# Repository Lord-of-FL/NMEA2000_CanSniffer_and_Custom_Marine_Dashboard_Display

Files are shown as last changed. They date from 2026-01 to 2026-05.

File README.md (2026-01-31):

Hi, 

Welcome to CanSniffer & Mini Screen build MK1, this project came from the desire to interact with my boat’s network, sniff data and display on my own custom screen with custom graphics. 
NOTE: This was all ChatGPT vibe coded, I am not a software engineer, I’m more of a 12V electronics / Cad guy who was feeling like trying something new. As a result this code is likely not optimized and not fit for commercial use. Please use it at your own risk and
DO NOT USE THIS HARDWARE OR CODE FOR ANY CRITICAL INSTUMENTATION DISPLAYS

Now that’s out of the way, the system architecture is split into 2 halves, the Arduino based CanSniffer takes the data off the NMEA2000 Network, using a CAN reading card, grabs data out of the relevant PGN’s and finally outputs a CSV string over USB of 4 values that the Pi is expecting to display on the UI.  

Currently it is set up for single frame reading of the Trim % and RPM PGN. It uses fast packet to decode the PGN for fuel consumption rate and it uses FF12 which is proprietary SUZUKI PGN used for shift indication. That PGN was decoded during the DEV process for my specific setup of a single Fly-by-wire shift and throttle controller, one SMG4 MFD and a DF200 single outboard. This may or may not work with other setups of SUZUKI hardware.This is an experimental hobby project, not production-grade, as I said before and chatgpt handled the code work on this project. I recommend having a laptop collecting the log data when using the software. There is also a little I2C OLED screen on the CanSniffer itself you can use for whatever. 

In my experience this build has been stable and I am happy with it, of course anyone who has more experience will be able to add features or optimizations. Good luck, I would love to hear from anyone who is working on this project and what you end up making. 

This project was developed and tested on:
- Suzuki DF200 outboard
- Single fly-by-wire shift/throttle controller
- One SMG4 MFD
- Arduino Nano + MCP2515 module
- Small I2C OLED screen on the sniffer unit

The current firmware is configured for:
- **Trim % + RPM** (single-frame decoding)
- **Fuel Rate** (Fast Packet decoding, PGN 127489)
- **Shift / Gear Indicator** via proprietary Suzuki PGN:
- **PGN FF12 (65298)** — Suzuki-specific gear data

## Licensing
- Software (Arduino + Pi code): GPL v3  
- Hardware/design files (STLs, wiring): CC BY-SA 4.0

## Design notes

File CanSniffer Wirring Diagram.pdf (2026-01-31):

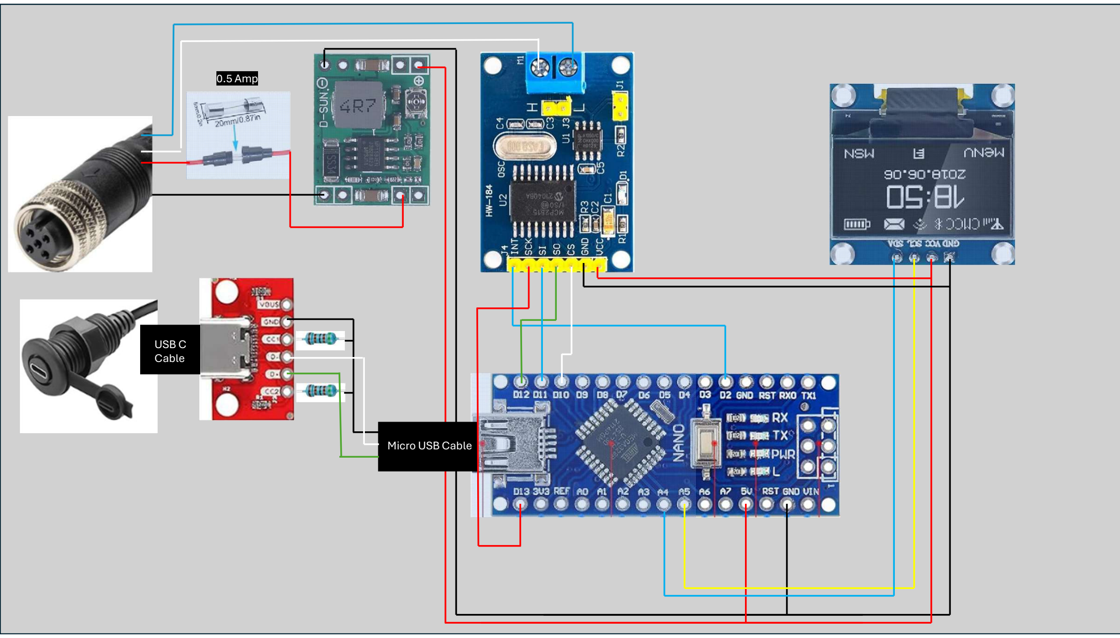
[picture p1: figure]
USB C Cable; Micro USB Cable; 0.5 Amp

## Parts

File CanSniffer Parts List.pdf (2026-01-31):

# CanSnier Part List

Mini Nano V3.0 ATmega328P

### 5 Pcs 0.96 Inch OLED I2C IIC Display Module 12864 128x64 Pixel SSD1306 Mini Self-

Luminous OLED Screen Board Compatible with Arduino Raspberry Pi

WWZMDiB 3 Pcs MCP2515 TJA1050 CAN Bus Module SPI Interface Compatible with for Arduino Raspberry Pi ESP32 STM (CAN Bus Controller + Receiver)

AITRIP 8 Pack Mini MP1584EN DC-DC Buck Converter Adjustable Power Supply Module 24V to 12V 9V 5V 3VCompatible with Arduino Raspberry Pi

100pcs 5.1K ohm Resistor 1/4w (0.25 Watt) ±1% Tolerance Metal Film Fixed Resistor

DIANN 5pcs USB Type-C Breakout Board Serial Basic Breakout Female Connector Type PCB Converter Board

NMEA2000 Cable (Choose the length you need to get from your T to the can-snier)

QIANRENON 5Gbps USB C Threaded Fixed Short Cable USB Type C 3.0 Male to Female Embedded Charging Data Adapter Cable USB C 3.0 Bulkhead Mount Connector PD 60W 3A, for Furniture/Car/RV, 30cm/11.8in

Fuse Holders (Use a .5 amp)

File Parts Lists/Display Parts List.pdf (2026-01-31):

# Display Part List

PENGLIN 2PCS Waterproof USB 3.0 Panel Mount Coupler, IP67 USB Pass Through Connector, Female to Female Bulkhead Extension Adapter

AuviPal USB C 90 Degree Adapter (2 Pack), Up and Down Right Angle L Shape USB Type C Male to Female Connector for Steam Deck, ROG Ally, MacBook, Tablet, Phone and More - Black

cablecc 4pcs/lot 90/360 Degree Angled Type USB-C USB2.0 Type C Female to Micro USB Male Power Data Adapter

12V USB Car Socket, 3-Port Marine Aluminum USB Quick Charge Waterproof Cigarette Round USB C 12V Outlet for Car Golf Cart Boat Marine Bus Truck RV Marine Motorcycle etc(2QC+1PD(1Pack))

8K 90 Degree HDMI 2.1 Adapter 2 Pack, (Up and Down) Right Angle HDMI Male to Female HDMI L-Shaped Connector Extender Support 8K@60Hz,4K@120Hz for Google Chrome Cast, Roku Stick, Wall TV, Laptop and PC

12pcs 7mm 3V-6V-12V-24V-230V/1A Prewired Mini Momentary Push Button,SPST Nomal Open ON/O 2 Pin Round Button for Model Railway Hobby

LED Latching Push Button Switch, Aluminum Alloy, IP67 Waterproof 5-24V 20A 1NO, with Wire Socket Plug (1, Blue, 19mm)

5inch WSVGA 1024 * 600 High Pixel Display 100% SRGB Without Touch Panel HDMI-Compatible Module for Raspberry pi 3/3B/3B+/4/4B Orange pi Banana pi MINI PC

New Raspberry Pi 3 Model B+ Board (3B+) Raspberry PI 3B+ (1GB) (3B Plus)

SP13 2pin/3pin/4pin/5pin/6pin/7pin/ 9pin Panel Mount Waterproof Aviation Connectors Plug Socket IP67, Electrical Cable Wire Connector (2pin, Panel Mount-Plug(Male)&Socket(Female))

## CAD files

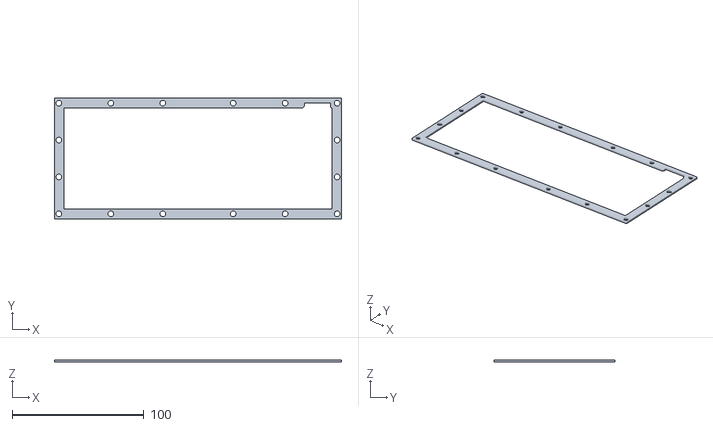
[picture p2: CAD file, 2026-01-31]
3D_Prints/CanSniffer Gasket 3D Print.stl
217.4 x 91.4 x 1.57

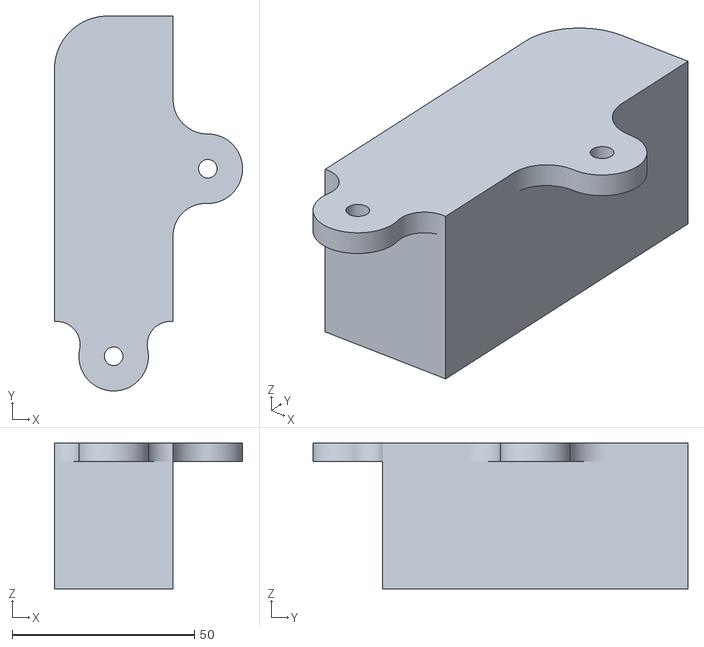
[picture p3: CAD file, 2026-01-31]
CanSniffer Mount L 3D Print.stl
51.6 x 102.8 x 39.9

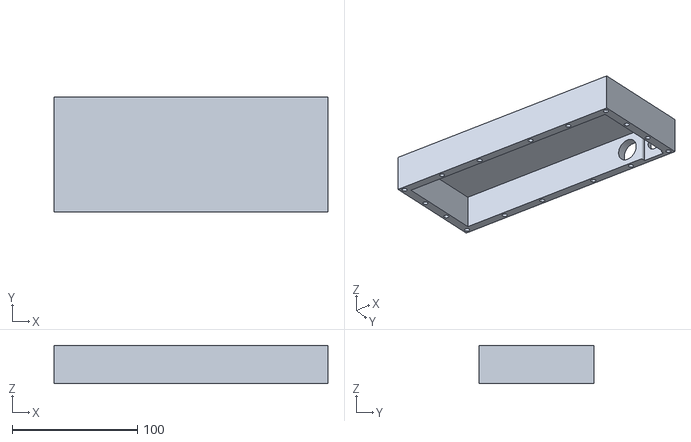
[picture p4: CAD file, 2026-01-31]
3D_Prints/CanSniffer Body 3D Print.stl
218.4 x 91.4 x 30.5

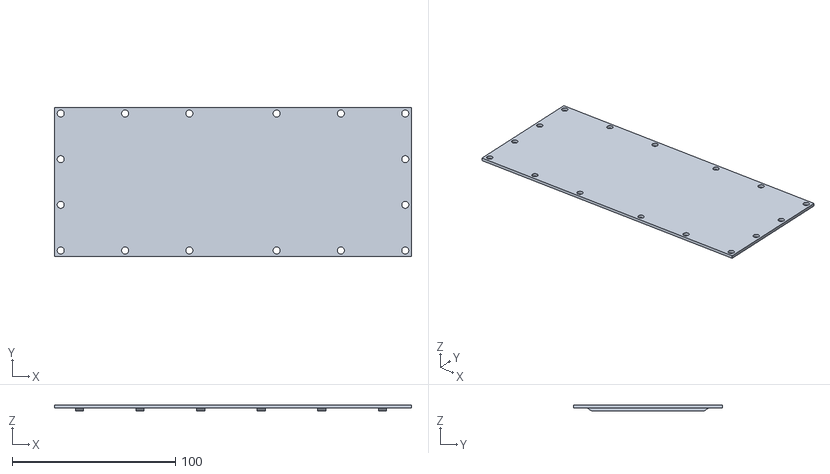
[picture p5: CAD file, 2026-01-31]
CanSniffer Lid 3D Print.stl
218.4 x 91.4 x 3.81

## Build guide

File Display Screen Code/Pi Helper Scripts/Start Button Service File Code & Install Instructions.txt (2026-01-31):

Step 1
sudo mkdir -p /etc/systemd/system

Step 2
sudo nano /etc/systemd/system/button_listener.service

Step 3
[Unit]
Description=GPIOZero Button Listener Service
After=network.target

[Service]
Type=simple
ExecStart=/usr/bin/python3 /home/mikestrohofer/Scripts/Button_listener.py
WorkingDirectory=/home/mikestrohofer/Scripts
User=mikestrohofer
Group=mikestrohofer
Restart=on-failure

[Install]
WantedBy=multi-user.target

Step 4

sudo systemctl daemon-reload

sudo systemctl enable button_listener.service

sudo systemctl start button_listener.service

sudo systemctl status button_listener.service

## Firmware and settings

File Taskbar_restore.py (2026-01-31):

#!/usr/bin/env python3
import os
import time
import subprocess

def restore_taskbar():
    print("Attempting to restore taskbar...")
    # Optional delay in case you need to allow transient issues to settle
    time.sleep(2)
    
    # Prepare a copy of the current environment and set X display variables.
    env = os.environ.copy()
    env["DISPLAY"] = ":0"
    env["XAUTHORITY"] = "/home/mikestrohofer/.Xauthority"
    
    # Log the environment settings for debugging
    print("Environment for taskbar restoration:")
    print("DISPLAY =", env.get("DISPLAY"))
    print("XAUTHORITY =", env.get("XAUTHORITY"))
    
    # Attempt to run the taskbar restoration command
    try:
        process = subprocess.Popen(
            ["/usr/bin/wf-panel-pi"],
            env=env
        )
        print("wf-panel-pi launched with PID:", process.pid)
    except Exception as e:
        print("Error launching wf-panel-pi:", e)

if __name__ == '__main__':
    restore_taskbar()

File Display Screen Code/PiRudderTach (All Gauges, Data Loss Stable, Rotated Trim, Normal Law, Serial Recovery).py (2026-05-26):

#!/usr/bin/env python3
import os
import time
import subprocess
import pygame
import serial
import math
import RPi.GPIO as GPIO

time.sleep(5)
os.environ["DISPLAY"] = ":0"

BUTTON_PIN = 18
GPIO.setmode(GPIO.BCM)
GPIO.setup(BUTTON_PIN, GPIO.IN, pull_up_down=GPIO.PUD_UP)

pygame.init()
info = pygame.display.Info()
print("Detected screen resolution:", info.current_w, "x", info.current_h)

SCREEN_WIDTH = info.current_w
SCREEN_HEIGHT = info.current_h
screen = pygame.display.set_mode((SCREEN_WIDTH, SCREEN_HEIGHT), pygame.FULLSCREEN)
pygame.display.set_caption("Gauge Display")
clock = pygame.time.Clock()

GAUGE_TOP_CENTER = (SCREEN_WIDTH // 2, SCREEN_HEIGHT // 4 - 15)
GAUGE_BOTTOM_CENTER = (SCREEN_WIDTH // 2, SCREEN_HEIGHT * 3 // 4 + 15)
smaller_dim = min(SCREEN_WIDTH, SCREEN_HEIGHT)
GAUGE_RADIUS = int(smaller_dim * 0.3)

BACKGROUND_COLOR = (81, 194, 210)
BLACK = (0, 0, 0)
RED = (255, 0, 0)
GREEN = (0, 255, 0)
GRAY = (255, 255, 255)
WHITE = (255, 255, 255)

# ================= SERIAL CONFIG =================
SERIAL_PORT = "/dev/ttyUSB0"
SERIAL_BAUD = 57600

# If we don't receive a GOOD frame for this long, we consider data "stale" and go to no-data UI.
DATA_STALE_SECONDS = 1.0

# If serial isn't present, retry opening periodically.
SERIAL_RETRY_SECONDS = 2.0

# If the serial reader goes stale while the Arduino is still alive,
# force a clean serial reconnect periodically.
SERIAL_RECOVERY_SECONDS = 3.0

ser = None
last_serial_try_time = 0.0
last_good_frame_time = 0.0
last_serial_recovery_time = 0.0

heading_font = pygame.font.SysFont("Arial", int(smaller_dim * 0.07))

rudder_angle = 180                 # centered
engine_rpm = 3000                  # centered
smoothed_engine_rpm = 3000         # centered
smoothed_rudder_angle = 180        # centered
shift_indicator = None
fuel_consumption = None


def map_value(value, in_min, in_max, out_min, out_max):
    return (value - in_min) * (out_max - out_min) / (in_max - in_min) + out_min


def try_open_serial():
    """Try to open the serial port. Safe if Arduino is off/unplugged."""
    global ser, last_serial_try_time
    now = time.monotonic()
    if ser is not None:
        return
    if now - last_serial_try_time < SERIAL_RETRY_SECONDS:
        return

    last_serial_try_time = now
    try:
        ser = serial.Serial(SERIAL_PORT, SERIAL_BAUD, timeout=0.05)
        # Non-blocking-ish read:
        ser.reset_input_buffer()
        print(f"Serial opened: {SERIAL_PORT} @ {SERIAL_BAUD}")
    except Exception:
        ser = None
        # Keep it quiet-ish; uncomment if you want logs:
        # print(f"Serial open failed: {e}")


def close_serial():
    global ser
    try:
        if ser is not None:
            ser.close()
    except Exception:
        pass
    ser = None


def set_no_data_state():
    """UI defaults when no fresh serial data is available."""
    global rudder_angle, engine_rpm, smoothed_engine_rpm, smoothed_rudder_angle
    global shift_indicator, fuel_consumption

    # Center both needles as requested
    smoothed_rudder_angle = 180
    smoothed_engine_rpm = 3000

    rudder_angle = smoothed_rudder_angle
    engine_rpm = smoothed_engine_rpm

    # Show "-" in boxes
    shift_indicator = None
    fuel_consumption = None


def process_serial_data():
    global rudder_angle, engine_rpm, smoothed_engine_rpm, smoothed_rudder_angle
    global shift_indicator, fuel_consumption, last_good_frame_time, ser

    if ser is None:
        return

    try:
        latest_data = None

        # Drain all waiting serial lines and keep only the newest one.
        # This prevents the Pi from slowly falling behind or getting stuck
        # processing old/partial junk if the serial buffer gets weird.
        while ser.in_waiting > 0:
            raw = ser.readline()
            if not raw:
                break

            data = raw.decode("utf-8", errors="ignore").strip()
            if data:
                latest_data = data

        if latest_data is None:
            return

        values = latest_data.split(",")
        if len(values) < 4:
            return

        pot_value = int(values[0])
        pot_value2 = int(values[1])
        shift_indicator = int(values[2])
        fuel_consumption = float(values[3])

        new_rudder_angle = map_value(pot_value, 0, 4095, 240, 120)   # your existing mapping
        new_engine_rpm = map_value(pot_value2, 0, 4095, 0, 6000)

        alpha = 0.3
        smoothed_engine_rpm = alpha * new_engine_rpm + (1 - alpha) * smoothed_engine_rpm
        smoothed_rudder_angle = alpha * new_rudder_angle + (1 - alpha) * smoothed_rudder_angle

        rudder_angle = smoothed_rudder_angle
        engine_rpm = smoothed_engine_rpm

        # Mark fresh data time ONLY after a full valid parse
        last_good_frame_time = time.monotonic()

    except Exception as e:
        # If Arduino power drops mid-read, pyserial can throw. Drop serial and keep UI alive.
        print("Serial error:", e)
        close_serial()

def draw_water_waves(surface, t):
    num_waves = 22
    amplitude = 10
    period = 300
    speed = 0.0002
    for i in range(num_waves):
        base_y = 100 + i * 40
        phase = t * speed * (i + 1)
        points = []
        for x in range(0, SCREEN_WIDTH, 4):
            y = base_y + amplitude * math.sin(2 * math.pi * x / period + phase)
            points.append((x, y))
        pygame.draw.lines(surface, WHITE, False, points, 2)


def draw_dotted_arc(surface, center, radius, start_deg, end_deg, step_deg, dot_radius, color):
    for deg in range(start_deg, end_deg + 1, step_deg):
        theta = math.radians(deg)
        x = center[0] + math.cos(theta) * radius
        y = center[1] + math.sin(theta) * radius
        pygame.draw.circle(surface, color, (int(x), int(y)), dot_radius)


def draw_boat_shape(surface, center, scale=1.0):
    cx, cy = center
    left_bottom = (cx - 20 * scale, cy + 40 * scale)
    right_bottom = (cx + 20 * scale, cy + 40 * scale)
    left_deck = (cx - 10 * scale, cy - 20 * scale)
    right_deck = (cx + 10 * scale, cy - 20 * scale)
    control = (cx, cy - 60 * scale)
    bow_points = []
    num_points = 20
    for i in range(num_points + 1):
        tt = i / num_points
        x = (1 - tt)**2 * left_deck[0] + 2 * (1 - tt) * tt * control[0] + tt**2 * right_deck[0]
        y = (1 - tt)**2 * left_deck[1] + 2 * (1 - tt) * tt * control[1] + tt**2 * right_deck[1]
        bow_points.append((x, y))
    boat_points = [left_bottom] + bow_points + [right_bottom]
    pygame.draw.polygon(surface, BLACK, boat_points)
    pygame.draw.polygon(surface, GRAY, boat_points, 2)
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

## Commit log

2026-01-31 Rename CanSniffer Body 3D Print.stl to 3D_Prints/CanSniffer Body 3D Print.stl
    [CanSniffer Body 3D Print.stl]
2026-01-31 Rename CanSniffer Gasket 3D Print.stl to 3D_Prints/CanSniffer Gasket 3D Print.stl
    [CanSniffer Gasket 3D Print.stl]
2026-02-11 Rename Gear_RPM_Fuel_Shift_Working_Stability_MK1.ino to Arduino_Firmware_V1.1
    Firmware Stability Update that no longer 0's out values when there is a PGN decode error
2026-02-11 Rename CanSnifferCodeV1.1 to Arduino_Code/CanSnifferCodeV1.1
    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
2026-05-26 Add files via upload
    Updated Version with additional Stability Updates
    [PiRudderTach (All Gauges, Data Loss Stable, Rotated Trim, Normal Law, Serial Recovery).py]
